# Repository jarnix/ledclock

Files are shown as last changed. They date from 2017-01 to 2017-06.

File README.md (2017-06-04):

# Requirements

- 1 Raspberry Pi, raspbian installed, an IP address assigned to your Raspberry Pi on the wifi interface
- 1 Arduino Uno
- a led strip: [for example: this one from adafruit](https://www.adafruit.com/product/2842)
- a power supply for the led strip 5V / 2A, and the Arduino (5V / 1A), and the Raspberry Pi (also 5V / 1A), we will use just a single power supply (5V / 6A) for the actual build
- a 1000 µF capacitor and a 470 ohm resistor for the led strip
- a [cable](https://www.amazon.fr/gp/product/B003BZ00CE/ref=od_aui_detailpages01?ie=UTF8&psc=1) to connect your power supply to the grid 
- a structure (3d printed or something else like MDF) for attaching the led strip
- a box for putting the electronics inside (power supply + Arduino + Raspberry Pi), I chose [this box](http://www.creavea.com/coffre-en-bois-a-decorer-rectangulaire-165-cm_boutique-acheter-loisirs-creatifs_43684.html) to customize from a craft and hobbies site
- two small air fans [like these](https://www.amazon.fr/gp/product/B01M2YB9TV/ref=oh_aui_search_detailpage?ie=UTF8&psc=1) to evacuate the heat generated by the electronics
- a small usb cable to connect the Pi to the Arduino [like this one](https://www.seeedstudio.com/USB-Cable-Type-A-to-B-30CM-Black-p-1701.html)
- a Dremel to cut holes in the wood box

- some patience if you have a cat and even more if you have more than one

# Structure

I chose to use MDF since it's cheaper than 3d printing at this size.

### upper disc
- outer radius: 16.6 cm-
- inner radius: 12.8 cm
- height: 0.3 cm

### main disc
- outer radius: 15.92 cm
- inner radius: 12.8 cm
- height: 1 cm

### lower disc
- outer radius: 18.2 cm
- inner radius: 14.4 cm
- height: 1 cm

The discs look like this (with the led strip temporarily attached so you can understand):

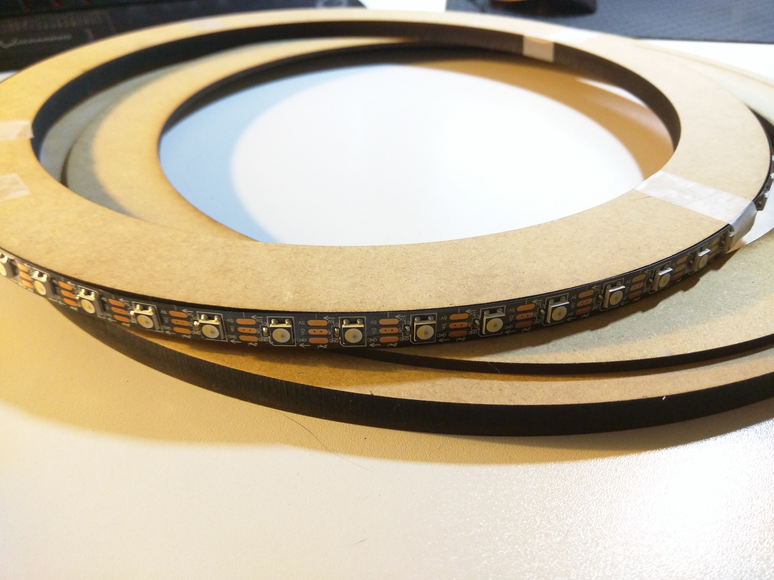
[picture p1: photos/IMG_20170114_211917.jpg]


I will paint them and glue them together so the upper disc covers the side of the led strip (so we only see the light and not the ugly leds), and the main disc will be use for hanging it to the wall (and maybe a mod with translucent cubes to spread the light, that may come later).

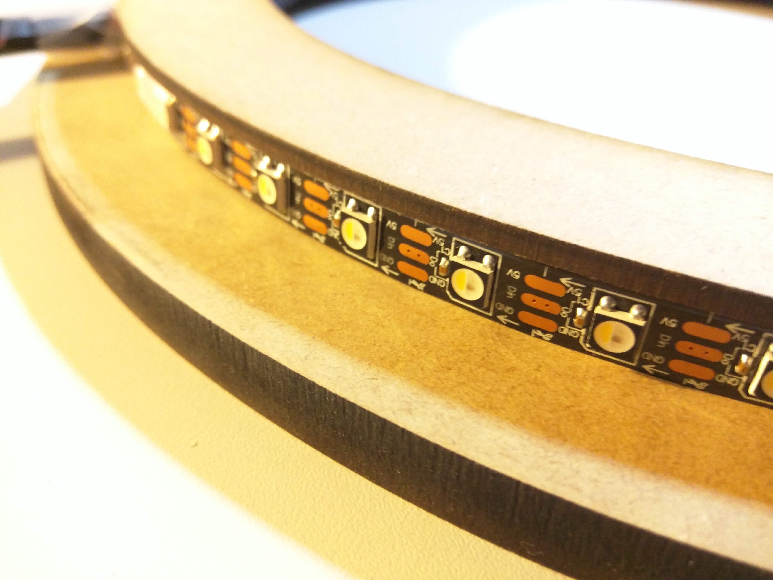
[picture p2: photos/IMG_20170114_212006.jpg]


# Wiring

The wiring may depend on the led strip that you chose. The [tutorial at Adafruit](https://learn.adafruit.com/adafruit-neopixel-uberguide/basic-connections) is good enough.

You will need a 1000 µF capacitor and a 470 ohm resistor.

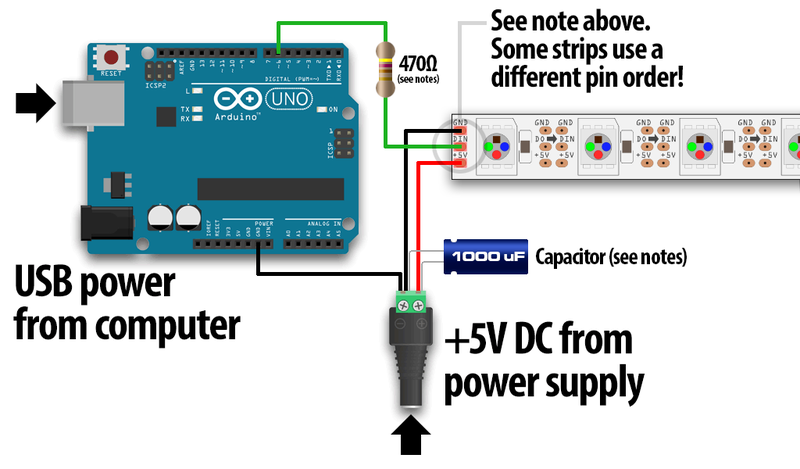
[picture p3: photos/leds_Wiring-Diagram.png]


# First test of the led strip connected to the Arduino

## Installation of the NeoPixel library

Please download the library for the Arduino for talking to the led strip here:
[Arduino Library Installation](https://learn.adafruit.com/adafruit-neopixel-uberguide/arduino-library-installation)

Recent versions of the Arduino IDE (1.6.2 and later) make library installation super easy via the Library Manager interface. From the Sketch menu, > Include Library > Manage Libraries...  In the text input box type in "NeoPixel". Look for "Adafruit NeoPixel by Adafruit" and select the latest version by clicking on the dropbox menu next to the Install button. Then click on the Install button. After it's installed, you can click the "close" button.

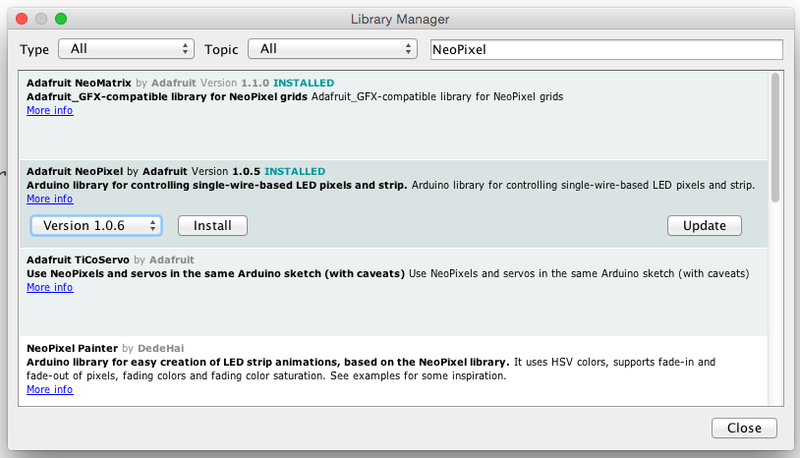
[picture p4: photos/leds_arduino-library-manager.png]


## Upload of the code

To check your wiring, we will use the example Arduino code located in the arduino/v0 folder.

Open the file arduino/v0/v0.ino with your Arduino IDE.

Upload the code to your Arduino connected to an usb port of your computer.

## Test

Plug:
- the wire of the data pin of the led strip to the pin number 6 of your Arduino
- the ground wire to one of the two ground pins of the Arduino
- your led strip to a 5V * 2A power supply.

You should see an animation. If not, check the wiring. The leds should do a animation like on this picture:

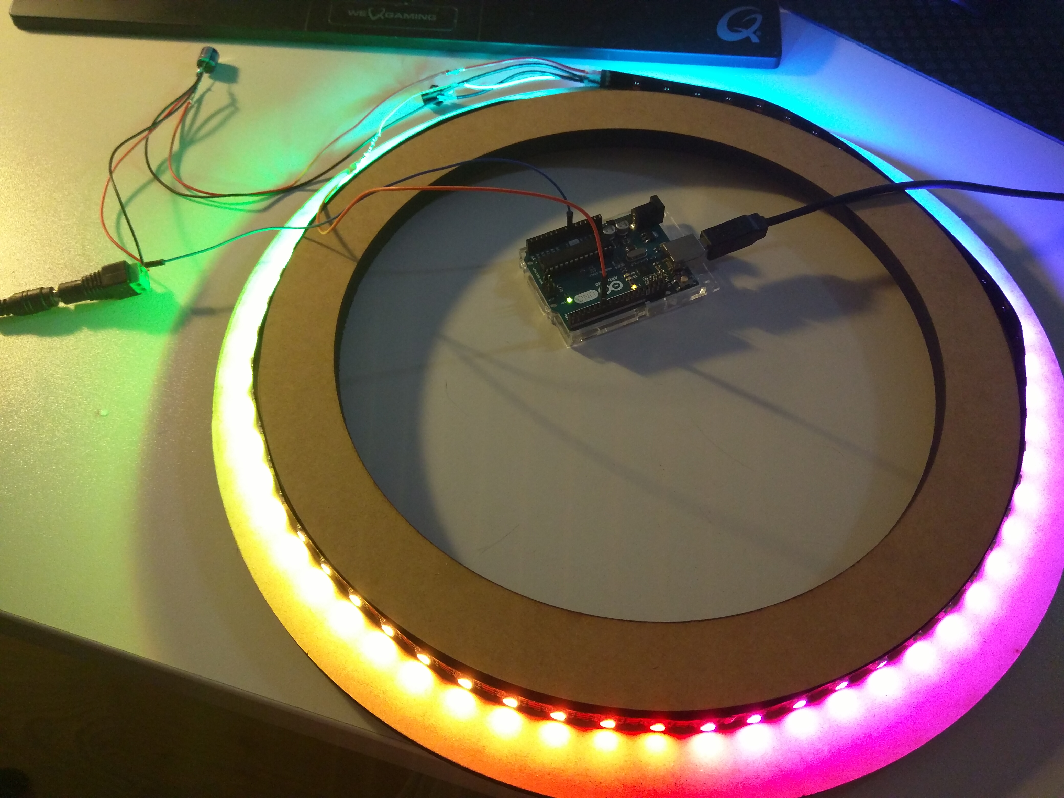
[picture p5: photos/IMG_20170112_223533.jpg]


# Build

## Wiring

We need to put the cables together in a tube to hide them and then plug all the things to a power source.

Isolate the cables connected to the led strip. Cut the cables and solder them with 3 other longer cables:
- one for power supply (red)
- one for the ground (a dark color)
- one for data (yellow, or white)

I used 2 meter cables, which should be enough excepted if you're a giant.

Cut the cables and keep this apart:
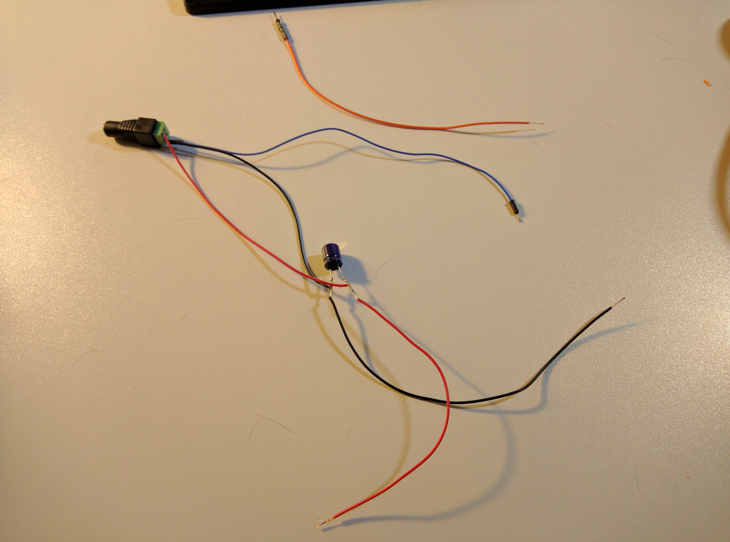
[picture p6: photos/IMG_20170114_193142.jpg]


Solder each cable to their respective brother. Put some tape around your soldering to isolate them.
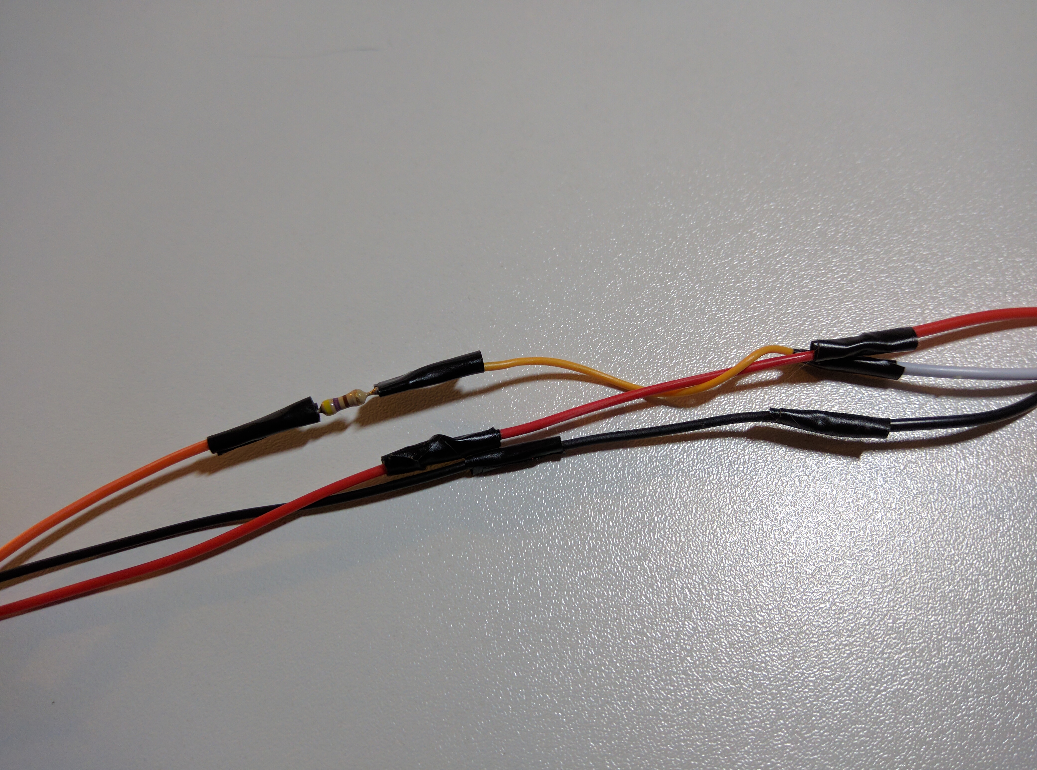
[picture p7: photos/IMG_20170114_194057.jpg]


Put the 3 long cables in a tube, like this one (you can do what you want, this is ugly I agree but it's temporary):

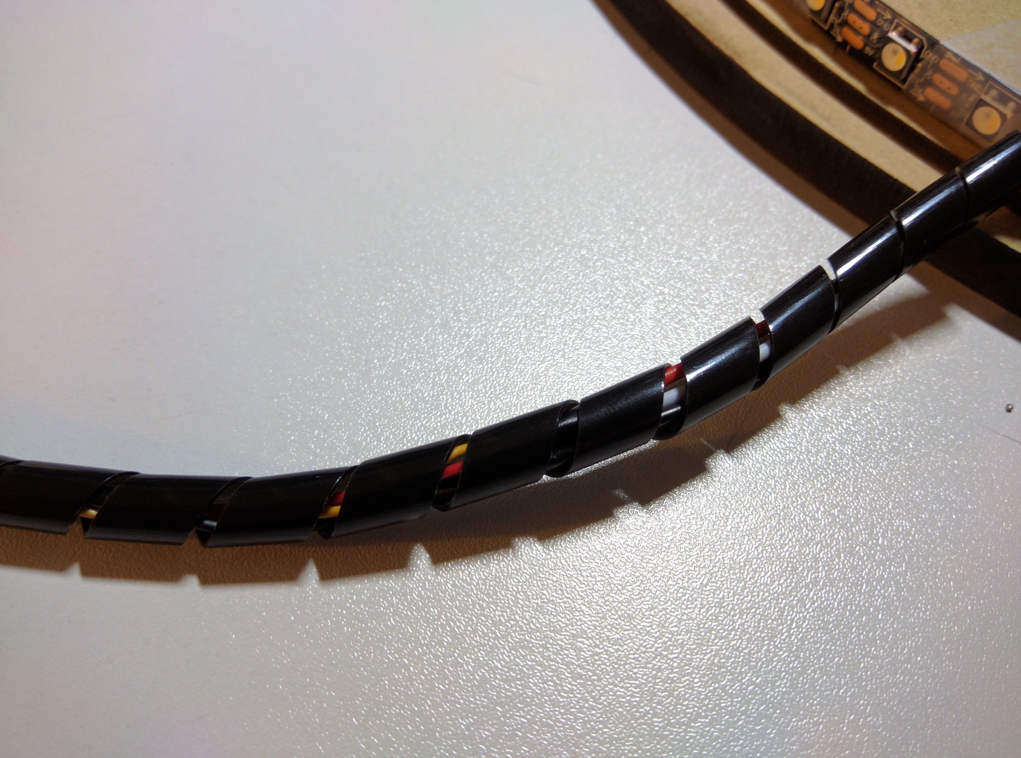
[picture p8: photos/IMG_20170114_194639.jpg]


## Power supply for the Arduino, the Raspberry Pi, and the led strip

During this step, be *extremely careful* when dealing with power supply from your outlet. Do not drink alcohol while doing this.

Be also careful not to invert the cables since you can burn the components of your Arduino and/or Raspberry Pi.

We are going to use a single power supply for all of them.

### Raspberry Pi

The Raspberry Pi needs 5V. The power IN is the pin n°2 and the ground is the pin n°6 as you can see on this photo:

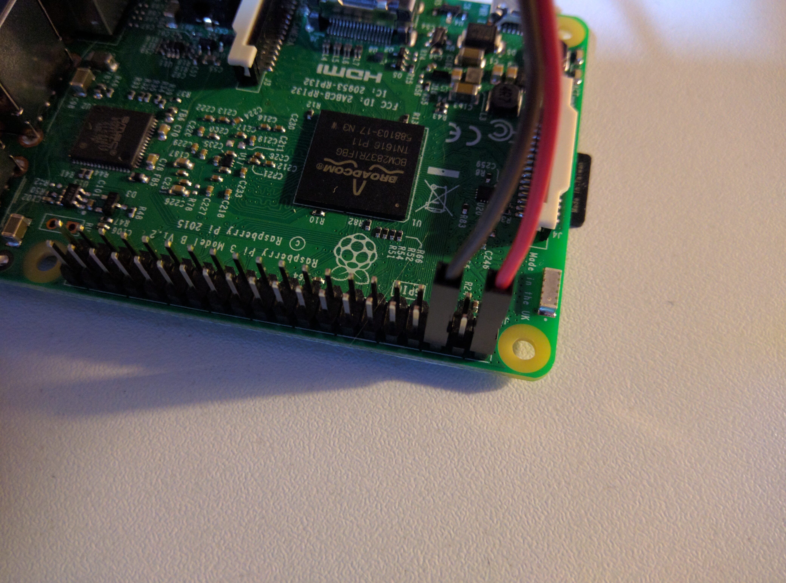
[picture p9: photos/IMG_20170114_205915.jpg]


### Arduino

The Arduino also needs 5V and has two pins named Vin for voltage IN and GND for ground:

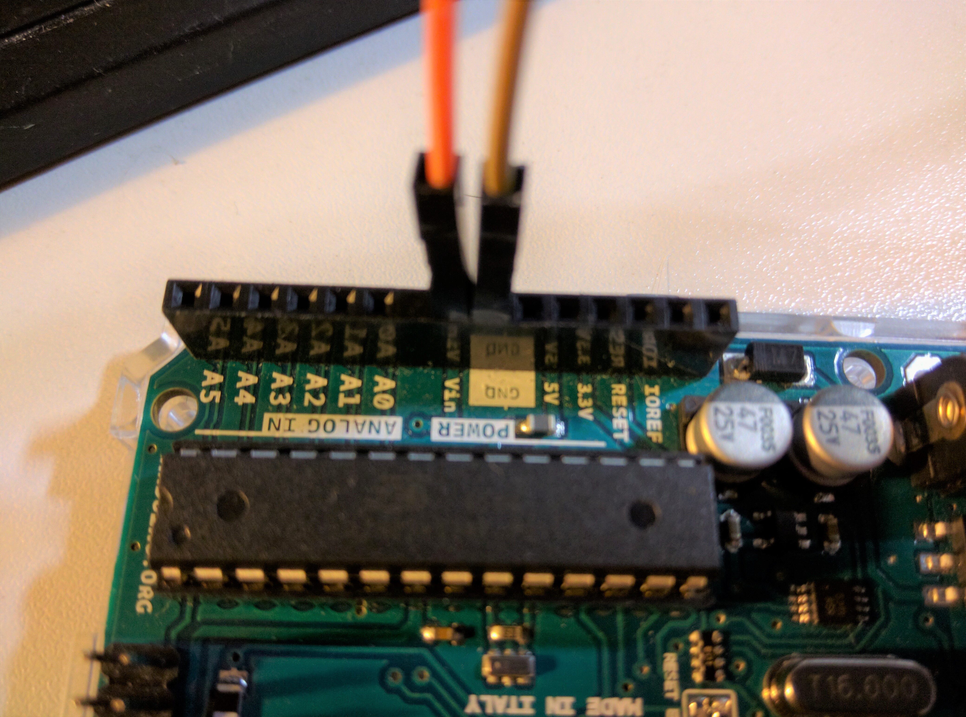
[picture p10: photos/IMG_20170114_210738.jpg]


### Led strip

The led strip requires 5V and needs to be connected also, use the corresponding 2 cables from the 3 connected to the led strip, so: the red one and the dark/black one.

# Customizing the box

The box will need a small hole for the power supply cable, and two larger ones for the air fans. I chose to put one fan on the right and one on top of the box.

I used a Dremel, the first basic model will do, [like this one](https://www.amazon.fr/Dremel-3000-15-rotatif-multi-usage-accessoires/dp/B0073R1IZ4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).

Cut the holes for the fans (at their exact shape) with a cutting disc, soften with sandpaper (use your Dremel again).

First hole for the power cord:

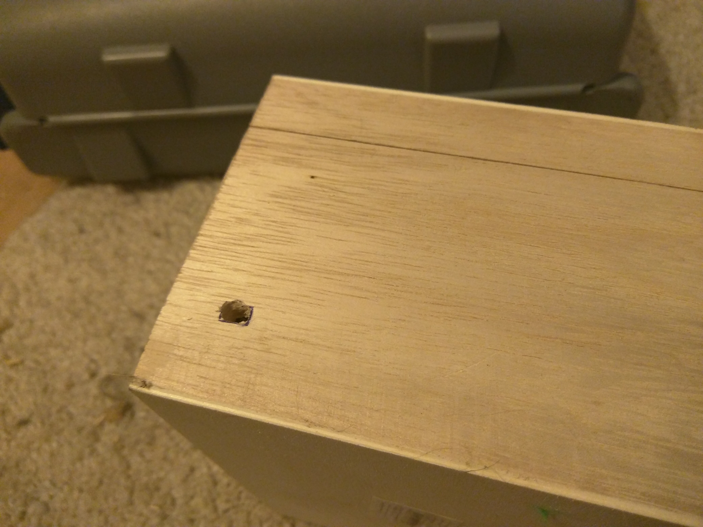
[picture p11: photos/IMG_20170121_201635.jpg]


Second and third hole for the fans:

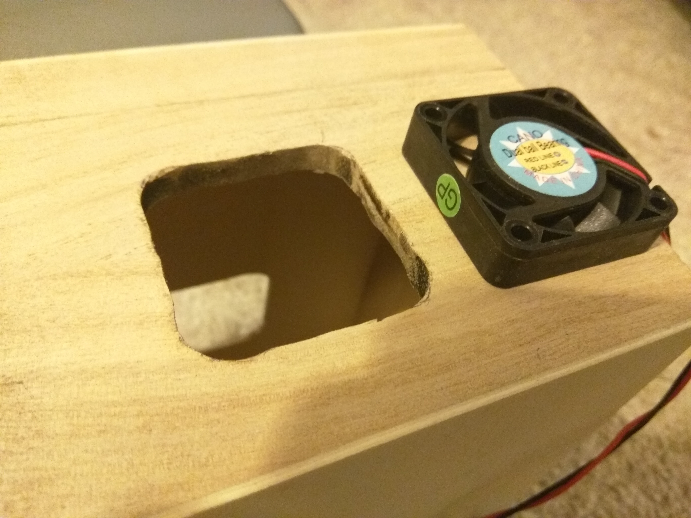
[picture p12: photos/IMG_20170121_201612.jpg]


So the box should look like that:

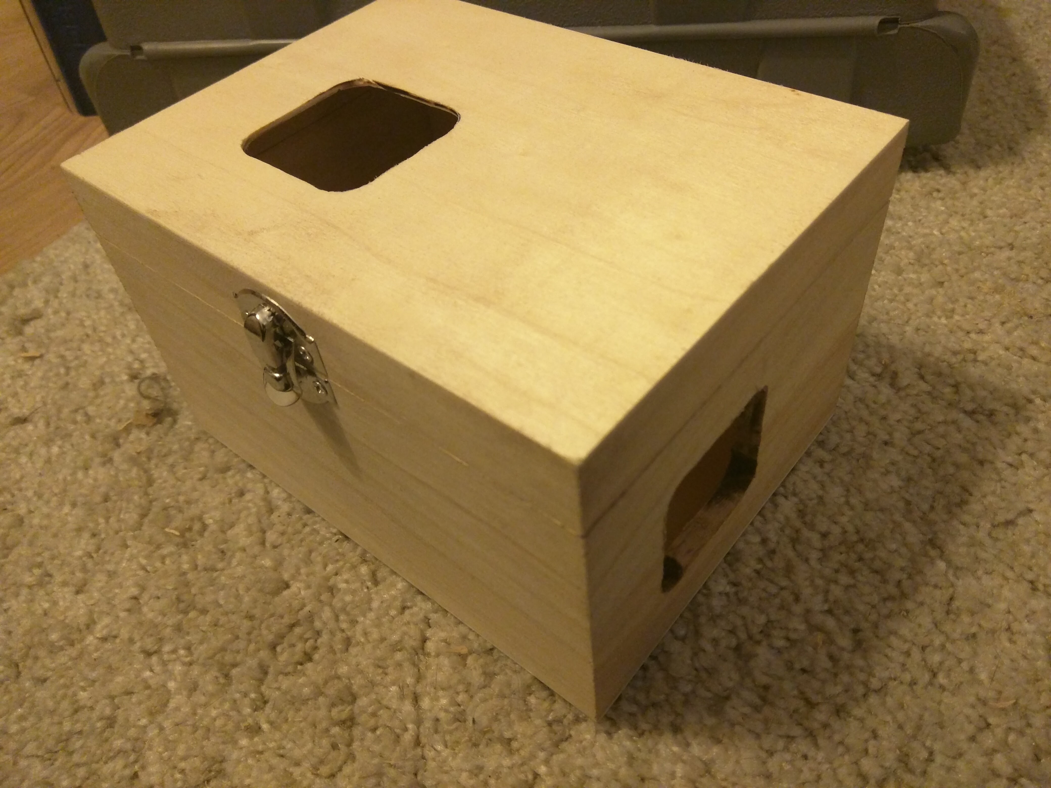
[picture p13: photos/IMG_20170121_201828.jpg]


## Attaching the fans to the box

To attach the fans to the box, I drew this object in 3d:

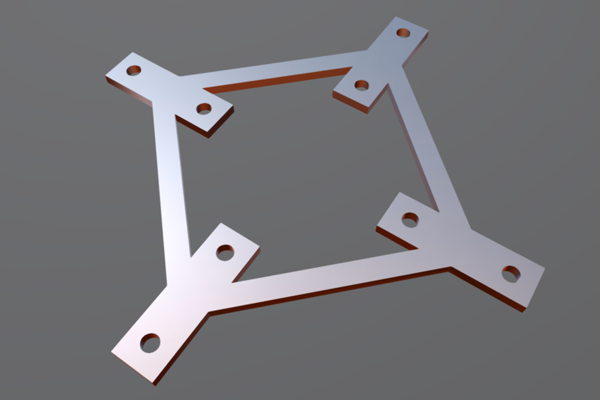
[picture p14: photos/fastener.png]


You can [see it on Sketchfab](https://sketchfab.com/models/18709e0d36ae43969bd89f850368d4fc).

And printed it (~ 10 €):

# Putting all together

## Paint if you want

I painted the discs in black, painted the box in black and used a black cord around the cables connecting the Arduino to the led strip.

## Connect the Arduino to the power source

The box on this photo contains only the power source, a tiny breadboard, the arduino, and two small fans that are not connected yet.

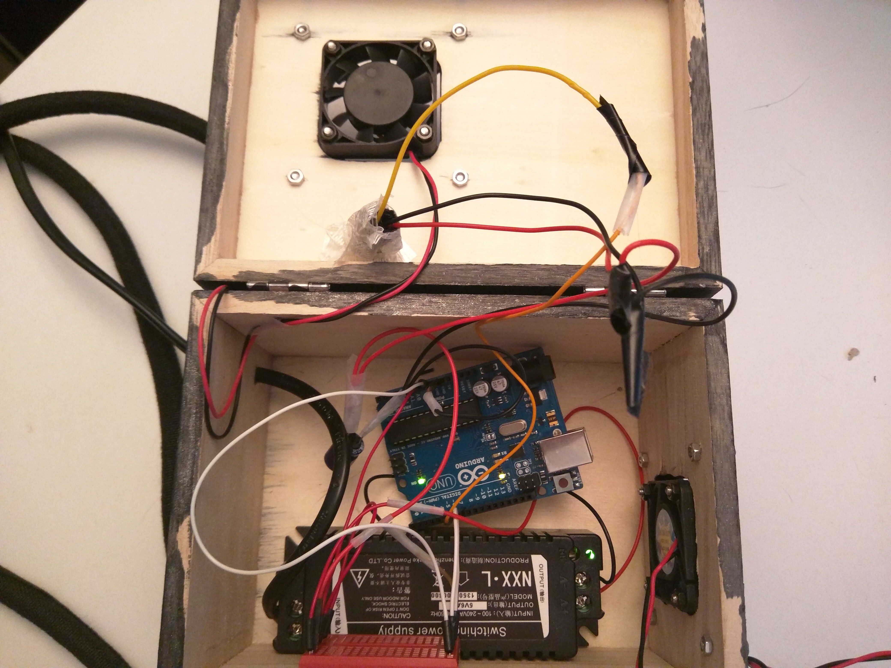
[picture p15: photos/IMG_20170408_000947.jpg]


## A preview of what it will be

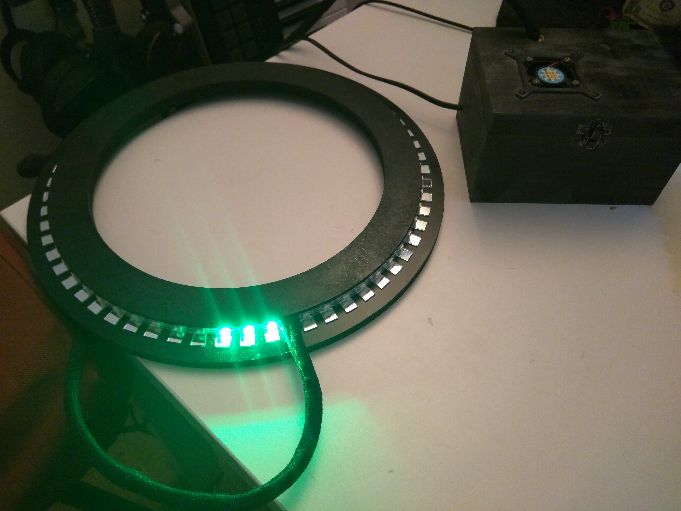
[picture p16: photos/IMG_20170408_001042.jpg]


## Connect the Pi to the power source

TODO

## Attaching the led strip to the main disc

Do not use glue, use double-sided adhesive tape, [like this one](https://www.amazon.fr/gp/product/B016UUOZBI/ref=oh_aui_search_detailpage?ie=UTF8&psc=1).

## 

---
The code
---

# First test of the clock

Use the code in arduino/v1/v1.ino

# Installation of the web application

TODO

## Installation of the packages and the webapp

TODO

# Usage

TODO

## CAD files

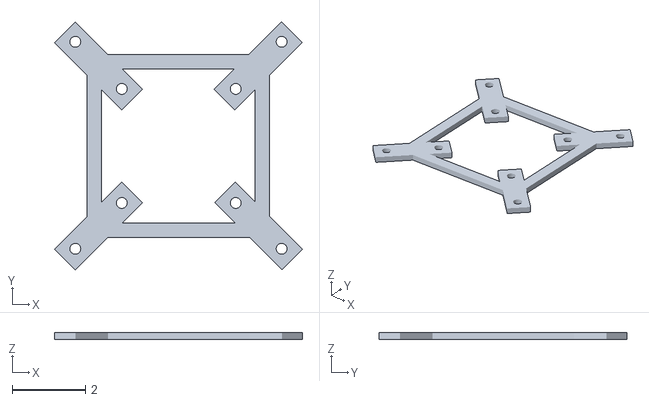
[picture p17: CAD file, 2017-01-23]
3d/fastener.stl
6.78 x 6.78 x 0.2

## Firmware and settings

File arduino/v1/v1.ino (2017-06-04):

#include <Time.h>
#include <TimeLib.h>

#include <Adafruit_NeoPixel.h>
#ifdef __AVR__
#include <avr/power.h>
#endif
/*
#include <TimeLib.h>
*/

#define PIN 6

#define TIME_HEADER  "T"   // Header tag for serial time sync message
#define TIME_REQUEST  7    // ASCII bell character requests a time sync message 

// Parameter 1 = number of pixels in strip
// Parameter 2 = Arduino pin number (most are valid)
// Parameter 3 = pixel type flags, add together as needed:
//   NEO_KHZ800  800 KHz bitstream (most NeoPixel products w/WS2812 LEDs)
//   NEO_KHZ400  400 KHz (classic 'v1' (not v2) FLORA pixels, WS2811 drivers)
//   NEO_GRB     Pixels are wired for GRB bitstream (most NeoPixel products)
//   NEO_RGB     Pixels are wired for RGB bitstream (v1 FLORA pixels, not v2)
//   NEO_RGBW    Pixels are wired for RGBW bitstream (NeoPixel RGBW products)
Adafruit_NeoPixel strip = Adafruit_NeoPixel(60, PIN, NEO_RGBW + NEO_KHZ800);

void setup() {
  Serial.begin(9600);
  // setSyncProvider(requestSync);  //set function to call when sync required
  Serial.println("Waiting for time sync message");
  // Messages consist of the letter T followed by ten digit time (as seconds since Jan 1 1970)
  // On Linux, you can use "date +T%s\n > /dev/ttyACM0" (UTC time zone)
  // ex: T1357041600

  setTime(1496605541);
  Serial.print(hour());
  Serial.print(":");
  Serial.print(minute());
  Serial.print(":");
  Serial.println(second());

  strip.begin();
  strip.show();

//  int8_t i;
//  for(i=0; i<90; i++) {
//    Serial.print(i);
//    Serial.print(" => ");
//    getIndexSixtyInCircle(i);
//  }
}


void loop() {
  // Some example procedures showing how to display to the pixels:
  //colorWipe(strip.Color(255, 0, 0), 50); // Red
  //colorWipe(strip.Color(0, 255, 0), 50); // Green
  //colorWipe(strip.Color(0, 0, 255), 50); // Blue
  //colorWipe(strip.Color(0, 0, 0, 255), 50); // White RGBW
  // Send a theater pixel chase in...
  //theaterChase(strip.Color(127, 127, 127), 50); // White
  //theaterChase(strip.Color(127, 0, 0), 50); // Red
  //theaterChase(strip.Color(0, 0, 127), 50); // Blue

  uint16_t totalMs = 0;

  // Serial.println("Hello Pi");

  if (Serial.available()) {
    processSyncMessage();
  }
  if (timeStatus() != timeNotSet) {

    for(uint8_t i = 0; i<60; i++) {
      clearStrip();

      showHour();
      showMinute();
      showSecond();
      showInSecond(i);
      
      strip.show();
      delay(8); // increment = 60 * 8
      totalMs += 8;
    }
    delay(1000 - totalMs); // missing milliseconds
  }

  /*
  rainbow(20);
  rainbowCycle(20);
  theaterChaseRainbow(50);
  */
}

void processSyncMessage() {
  unsigned long pctime;
  const unsigned long DEFAULT_TIME = 1357041600; // Jan 1 2013

  if (Serial.find(TIME_HEADER)) {
    pctime = Serial.parseInt();
    if (pctime >= DEFAULT_TIME) { // check the integer is a valid time (greater than Jan 1 2013)
      setTime(pctime); // Sync Arduino clock to the time received on the serial port
    }
  }
}

time_t requestSync()
{
  Serial.write(TIME_REQUEST);
  return 0; // the time will be sent later in response to serial mesg
}

void clearStrip() {
  for(uint8_t i = 0; i<60; i++) {
    strip.setPixelColor(i, strip.Color(0, 0, 0, 0));
  }
}

void showInSecond(uint8_t ledIndex) {
  int8_t indexOut = getIndexSixtyInCircle(second() + ledIndex);
//  Serial.print("inSecond : ");
//  Serial.print(second() + ledIndex);
//  Serial.print(" => ");
//  Serial.println(indexOut);
  strip.setPixelColor(indexOut, strip.Color(0, 0, 0, 10));
}

void showSecond() {
  int8_t nbSeconds = second();
  for(int8_t secondLed = nbSeconds; secondLed <= nbSeconds + 1; secondLed++) {
    strip.setPixelColor(getIndexSixtyInCircle(secondLed), strip.Color(253, 231, 76, 0));
  }
}

void showMinute() {
  int8_t nbMinutes = minute();
  for(int8_t index = nbMinutes - 2; index <= nbMinutes + 1; index++) {
    strip.setPixelColor(getIndexSixtyInCircle(index), strip.Color(91, 192, 235, 0));
  }
}

void showHour() {
  int8_t nbHours = hour();
  int8_t indexHours = getIndexTwelveInCircle(nbHours);
  for(int8_t index = indexHours - 2; index <= indexHours + 1; index++) {
    strip.setPixelColor(getIndexSixtyInCircle(index), strip.Color(220, 52, 235, 0));
  }
}

// for minutes and seconds
uint8_t getIndexSixtyInCircle(int8_t index) {
//  Serial.print("sixty : ");
  int8_t indexOut;
  indexOut = index;
  if(index < 0) {
    indexOut = 60 + index;
  }
  if(index > 60) {
//    Serial.print(" (> 60) ");
    indexOut = index - 60;
  }
  if(indexOut < 30) {
    indexOut = 30 + indexOut;
  }
  else {
    indexOut = indexOut - 30;
  }
//  Serial.print(index);
//  Serial.print(" => ");
//  Serial.println(indexOut);
  return indexOut;
}

// for the hours
uint8_t getIndexTwelveInCircle(int8_t index) {
  int8_t indexOut;
  if(index > 12) {
    index = index - 12;
  }
  if (index  < 6) {
    indexOut = 30 + 5 * index;
  }
  else {
    indexOut =  5 * index - 30;
  }
  return indexOut;
}

// Fill the dots one after the other with a color
void colorWipe(uint32_t c, uint8_t wait) {
  for (uint16_t i = 0; i < strip.numPixels(); i++) {
    strip.setPixelColor(i, c);
    strip.show();
    delay(wait);
  }
}

void rainbow(uint8_t wait) {
  uint16_t i, j;

  for (j = 0; j < 256; j++) {
    for (i = 0; i < strip.numPixels(); i++) {
      strip.setPixelColor(i, Wheel((i + j) & 255));
    }
    strip.show();
    delay(wait);
  }
}

// Slightly different, this makes the rainbow equally distributed throughout
void rainbowCycle(uint8_t wait) {
  uint16_t i, j;

  for (j = 0; j < 256 * 5; j++) { // 5 cycles of all colors on wheel
    for (i = 0; i < strip.numPixels(); i++) {
      strip.setPixelColor(i, Wheel(((i * 256 / strip.numPixels()) + j) & 255));
    }
    strip.show();
    delay(wait);
  }
}

//Theatre-style crawling lights.
void theaterChase(uint32_t c, uint8_t wait) {
  for (int j = 0; j < 10; j++) { //do 10 cycles of chasing
    for (int q = 0; q < 3; q++) {
      for (uint16_t i = 0; i < strip.numPixels(); i = i + 3) {
        strip.setPixelColor(i + q, c);  //turn every third pixel on
      }
      strip.show();

      delay(wait);

      for (uint16_t i = 0; i < strip.numPixels(); i = i + 3) {
        strip.setPixelColor(i + q, 0);      //turn every third pixel off
      }
    }
  }
}

//Theatre-style crawling lights with rainbow effect
void theaterChaseRainbow(uint8_t wait) {
  for (int j = 0; j < 256; j++) {   // cycle all 256 colors in the wheel
    for (int q = 0; q < 3; q++) {
      for (uint16_t i = 0; i < strip.numPixels(); i = i + 3) {
        strip.setPixelColor(i + q, Wheel( (i + j) % 255)); //turn every third pixel on
      }
      strip.show();

      delay(wait);

      for (uint16_t i = 0; i < strip.numPixels(); i = i + 3) {
        strip.setPixelColor(i + q, 0);      //turn every third pixel off
      }
    }
  }
}

// Input a value 0 to 255 to get a color value.
// The colours are a transition r - g - b - back to r.
uint32_t Wheel(byte WheelPos) {
  WheelPos = 255 - WheelPos;
  if (WheelPos < 85) {
    return strip.Color(255 - WheelPos * 3, 0, WheelPos * 3);
  }
  if (WheelPos < 170) {
    WheelPos -= 85;
    return strip.Color(0, WheelPos * 3, 255 - WheelPos * 3);
  }
  WheelPos -= 170;
  return strip.Color(WheelPos * 3, 255 - WheelPos * 3, 0);
}
